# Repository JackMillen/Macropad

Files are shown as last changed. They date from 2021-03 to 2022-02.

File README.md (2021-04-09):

# Macropad
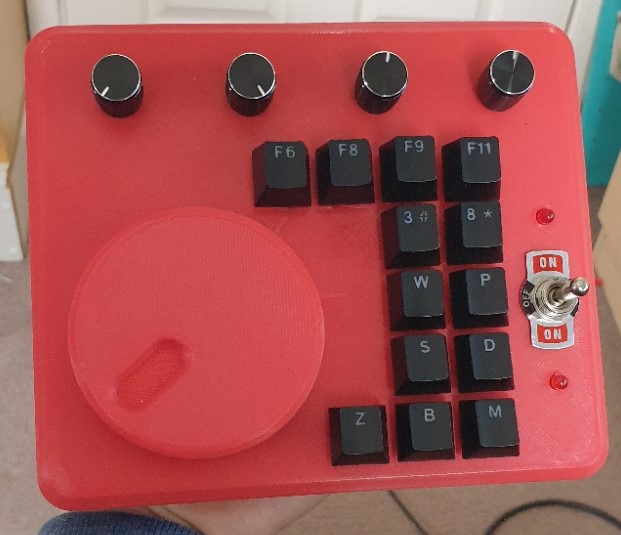
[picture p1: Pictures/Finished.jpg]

## What is it?
This is a small USB Keyboard with rotary encoders designed to have shortcuts assigned to them

It consists of a 3D printed enclosure with 4 Dials, 1 Big Wheel and 13 Mechanical KeySwitches. It also has a 3-Way Switch to switch between button layers. Its powered by a Teensy 4.0 (First time using a teensy and I am hooked)
## WTF was the warning in the description
I don't know what I'm doing. My code works, but it's not written in a way that is particularly understandable. the same applies for my 3D models, I haven't modelled this in a way that's easy to modify. It works enough for me. This project was designed for me to use and no-one else. The only reason this repository exists is a place to store the code. You can do with this how you want. Just be warned.
## Main Principal
The Macropad is recognised by the PC as a keyboard+mouse+joystick+serial device. The buttons on the Macropad output an f13-f24 keypress. Autohotkey listens for these keypresses and outputs the appropriate shortcut. I also added a 3-way switch to the Macropad so you can have different layers to the macros. I use the Serial output as a method of debugging, whenever you press a key, It outputs the letter assigned to the key and the current mode of the 3-Way switch (I know having an open Serial debug interface is a security risk, but it's a keyboard so whatever)
## Precompiled Firmware
I included the precompiled firmware I'm using alongside the source-code. The Firmware.hex is okay, however you might want to change the media keybindings. You almost definitly want to customise the autohotkey script (also both precompiled and Source-code available) since most keys open programs that I use often but most people will have never heard of (e.g. Cura) and the key set to output your email address just prints [EMAIL1] since I'm not sharing my personal email addresses (duh).
## Installing Precompiled Firmware
If for some unholy reason you want to use my precompiled firmware, here it is:
#### Macropad:
  1. Download [Teensy Loader](https://www.pjrc.com/teensy/teensy.exe)
  2. Download Firmware.hex from the Firmware directory
  3. Open Teensy Loader
  4. File/Open HEX file
  5. Press program button on teensy
  6. Press Upload
  7. DONE (LEDs should flash when powered on)
#### Windows:
  1. Win+R
  2. Run "shell:startup"
  3. Copy Macropad.exe into the folder
  4. DONE
## Test Firmware
When I was wiring the Macropad, I wanted to test the connections so I made a test program that just spits out sensor values over serial so they can be read by software like PuTTY or Arduino IDE. This helps find hardware issues with the Button Matrix and Rotary Encoders. Since I haven't uploaded wiring diagrams yet it probably isn't too useful
## Parts List
- 1x Big Wheel.stl
- 1x Top.stl
- 1x Holding Plate.stl
- 1x Base.stl
- 5x KY-040 Rotary encoders
- 1x 3-Way Switch
- 1x Teensy 4.0
- 13x Mechanical Keyswitch (I used Cherry MX Blue)
- 13x 1N4148 Diodes
- 13x Keycaps
- 7x Self Tapping Screws
- Thin insulated wire
- 2x LED
- 2x 200 Ohm Resistors

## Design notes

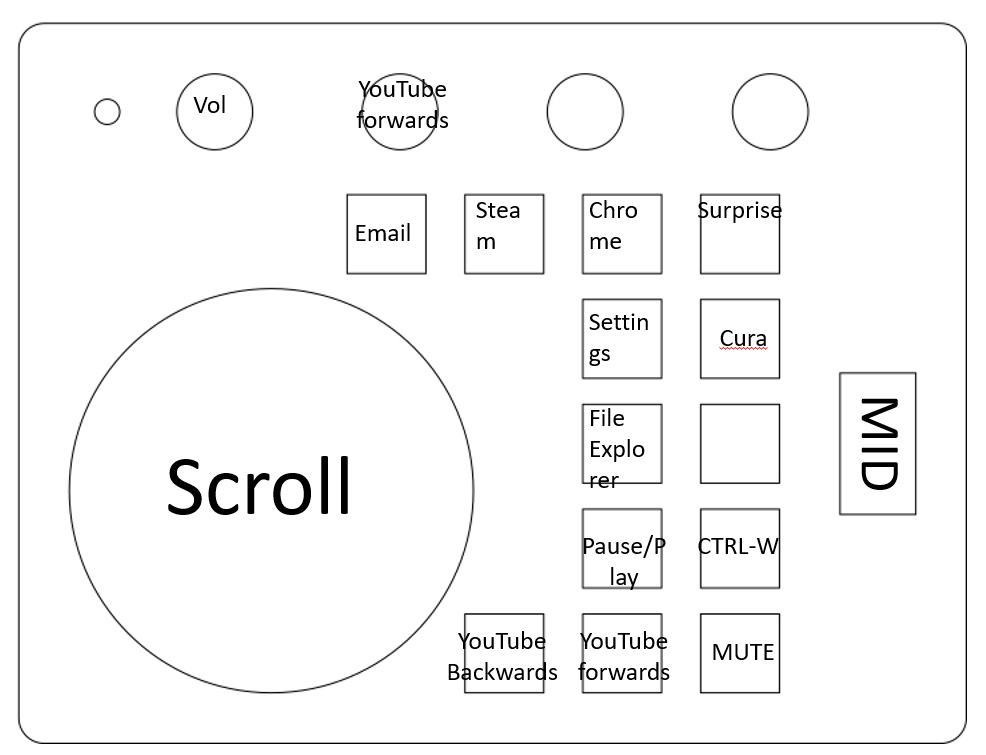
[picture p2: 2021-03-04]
Pictures/Controls.png

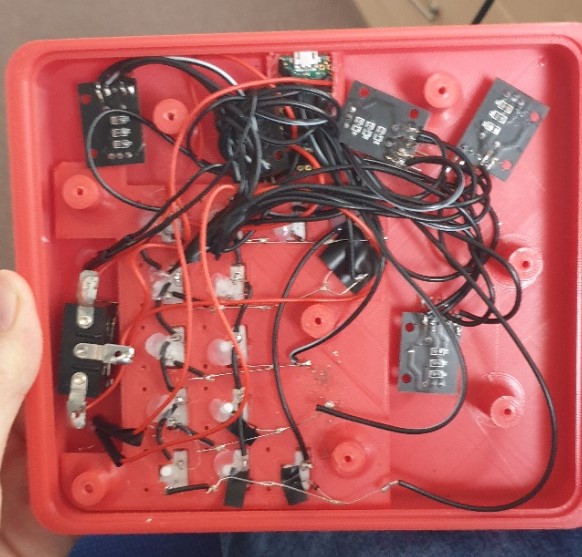
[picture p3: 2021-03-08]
Pictures/Open.jpg

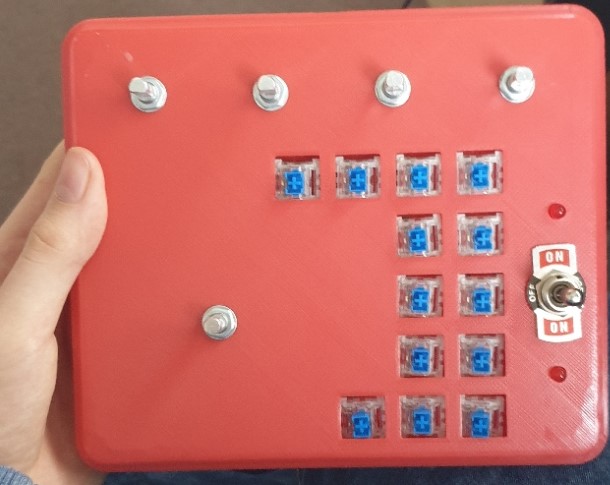
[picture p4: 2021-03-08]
Pictures/Without Keycaps.jpg

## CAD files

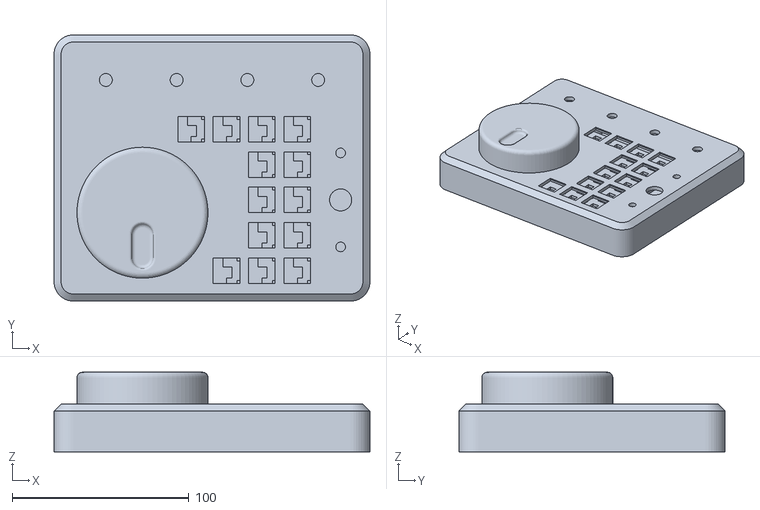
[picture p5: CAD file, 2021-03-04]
3D Models/Full Case.stl
178.6 x 150.5 x 45.0

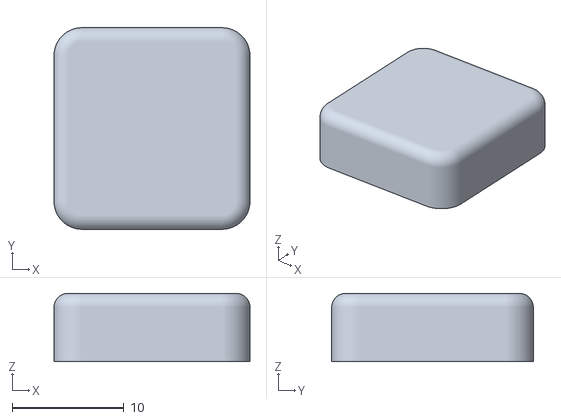
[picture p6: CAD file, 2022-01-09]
3D Models/Keycap.stl
17.5 x 18.0 x 6.10

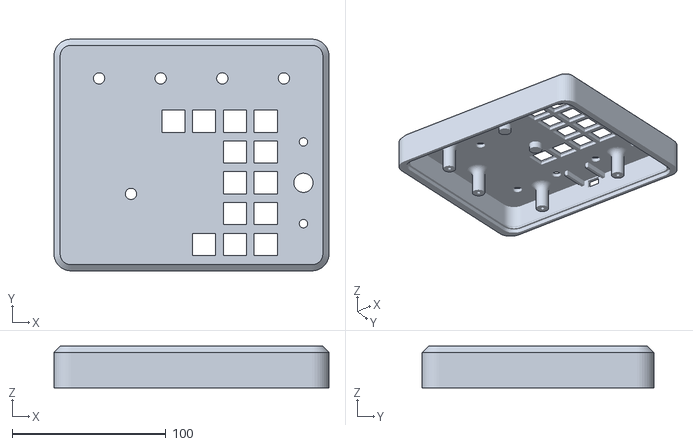
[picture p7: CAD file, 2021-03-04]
3D Models/Top.stl
178.6 x 150.5 x 27.0

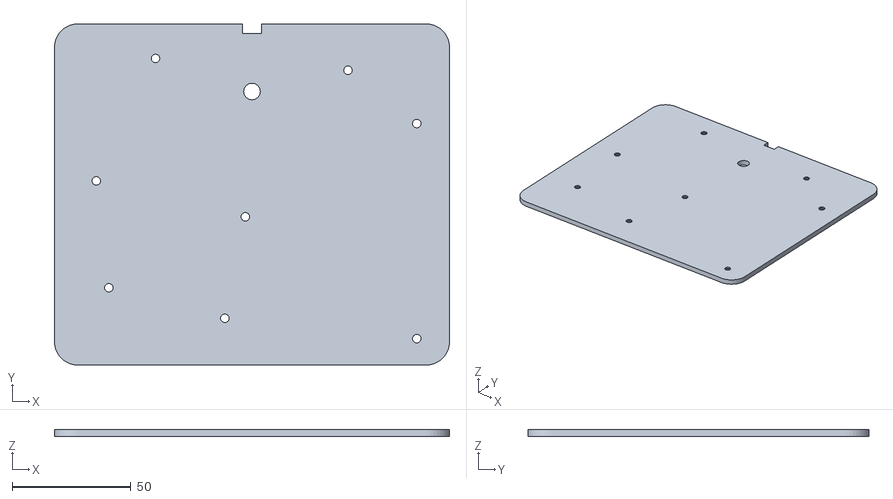
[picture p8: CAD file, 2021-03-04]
3D Models/Base.stl
166.6 x 143.9 x 3.00

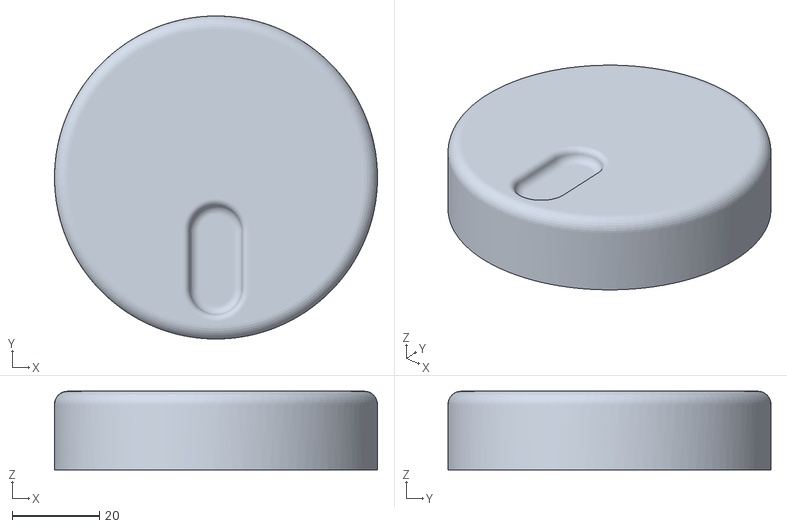
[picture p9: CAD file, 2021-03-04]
3D Models/Big Wheel.stl
74.0 x 74.0 x 18.0

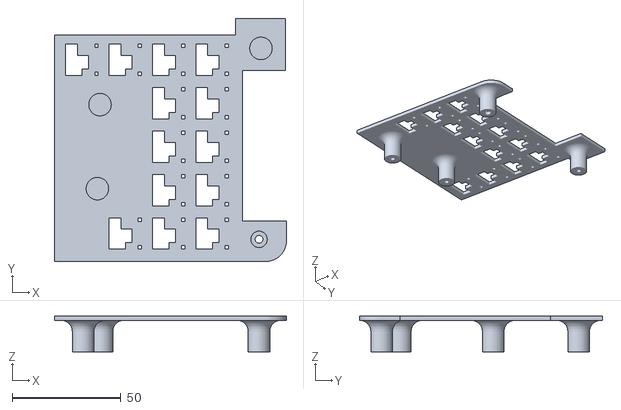
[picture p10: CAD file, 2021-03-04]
3D Models/Holding Plate.stl
106.8 x 111.9 x 16.5

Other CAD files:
3D Models/Macropad.f3d

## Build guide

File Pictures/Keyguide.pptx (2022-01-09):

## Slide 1

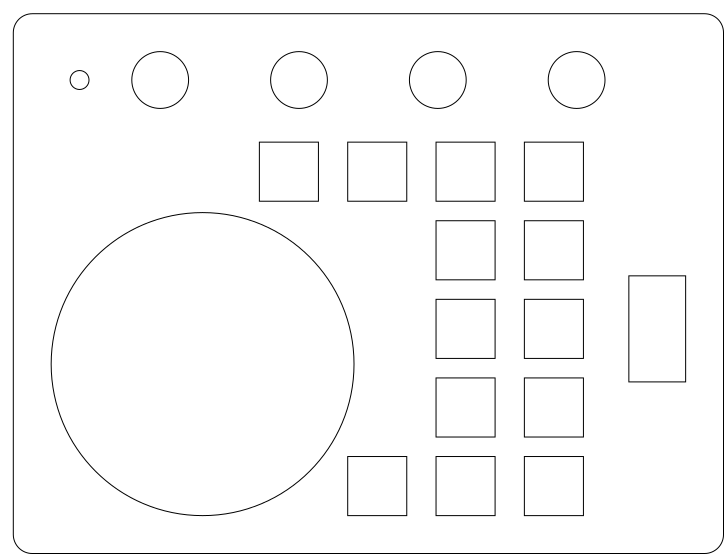
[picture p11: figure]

Vol

YouTube forwards

Email

Steam

Chrome

Task Manager

Rick Roll

Cura

Google Selected

Scroll

File Explorer

Pause/Play

MID

CTRL-W

Full Screen

YouTube Backwards

YouTube forwards

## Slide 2

Vol

Open Arduino

Reverse Indent

Upload

Indent

Scroll

Verify

UP

Monitor

IF

Plotter

Serial print
(SHIFT- no ln)

While

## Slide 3

DOWN

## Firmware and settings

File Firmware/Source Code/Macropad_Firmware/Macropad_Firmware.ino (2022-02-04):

#include <Keypad.h>
#include <Encoder.h>

//Start-Up LED Counter
int x = 0;

//Setting Key Row Variables
const int r1 = 1;
const int r2 = 2;
const int r3 = 3;
const int r4 = 4;
const int r5 = 5;


//Setting Key Column Variables
const int c1 = 6;
const int c2 = 7;
const int c3 = 8;


//Setting Rotary Encoder Variables
const int rot1A = 12;
const int rot1B = 11;
const int rot2A = 14;
const int rot2B = 15;
const int rot3A = 16;
const int rot3B = 17;
const int rot4A = 18;
const int rot4B = 19;
const int rot5A = 21;
const int rot5B = 20;


//Setting 3-Way Switch Variables
const int sw1 = 9; //Up
const int sw2 = 10; //Down


//Setting LED Variables
const int led1 = 22; //Up
const int led2 = 23; //Down


//Setting Encoder Classes
Encoder enc1(rot4A, rot4B); //Small 1
Encoder enc2(rot2A, rot2B); //Small 2
Encoder enc3(rot3A, rot3B); //Small 3
Encoder enc4(rot5A, rot5B); //Small 4
Encoder enc5(rot1A, rot1B); //Big Wheel

//Encoder Past
int past1 = 0;
int past2 = 0;
int past3 = 0;
int past4 = 0;
int past5 = 0;

/*
Code I copied and modified from the keypad library because I tried to code it myself but it was so 
inefficient that the serial bus was overwhelmed and I was loosing cycles. I'm so sorry I have failed you senpai
*/
const byte ROWS = 3; 
const byte COLS = 5; 
char hexaKeys[ROWS][COLS] = {
  {'D', 'F', 'H', 'J', 'M'},
  {'C', 'E', 'G', 'I', 'L'},
  {'B', 'A', 'M', 'N', 'K'}
};
byte rowPins[ROWS] = {c1, c2, c3}; 
byte colPins[COLS] = {r1, r2, r3, r4, r5}; 
Keypad customKeypad = Keypad(makeKeymap(hexaKeys), rowPins, colPins, ROWS, COLS); 


void setup() {
  //Starts Serial Debug Response
  Serial.begin(9600);

  //Sets LED and 3-Way pinmodes
  pinMode(sw1, INPUT);
  pinMode(sw2, INPUT);
  pinMode(led1, OUTPUT);
  pinMode(led2, OUTPUT);

  //Activating 3-Way PULLUP resistors
  digitalWrite(sw1, HIGH);
  digitalWrite(sw2, HIGH);

  //LED Starup Animation
  while (x != 4){
    digitalWrite(led1, HIGH);
    delay(100);
    digitalWrite(led2, HIGH);
    delay(100);
    digitalWrite(led1, LOW);
    delay(100);
    digitalWrite(led2, LOW);
    delay(100);
    x = x + 1;
  }

  //Serial Starup Message
  Serial.println("----------------------------------");
  Serial.println("-----Macropad V1.3 Alpha 2022-----");
  Serial.println("----------By Jack Millen----------");
  Serial.println("----------------------------------");
}

void loop() {

  
  //More sample code I copied and modified from the Keypad library
  char customKey = customKeypad.getKey();
  if (customKey){
    //Prints Mode when key is pressed
    if (digitalRead(sw1) == 0) {Serial.println("Mode: ▲");}
    else if (digitalRead(sw2) == 0) {Serial.println("Mode: ▼");}
    else {Serial.println("Mode: -");}
    
    //Prints what key has been pressed
    Serial.println(customKey);

    //Key actions
    if (digitalRead(sw1) == 0) {  // Switch UP
      if (customKey == 'A'){}
      if (customKey == 'B'){}
      if (customKey == 'C'){}
      if (customKey == 'D'){Keyboard.press(KEY_F21);Keyboard.release(KEY_F21);} //Open Arduino IDE
      if (customKey == 'E'){Keyboard.press(KEY_TAB);Keyboard.release(KEY_TAB);} //Indent
      if (customKey == 'F'){Keyboard.set_modifier(MODIFIERKEY_SHIFT);Keyboard.press(KEY_TAB);Keyboard.release(KEY_TAB);Keyboard.set_modifier(0);Keyboard.send_now();} //Reverse Indent
      if (customKey == 'G'){Keyboard.set_modifier(MODIFIERKEY_CTRL);Keyboard.press(KEY_R);Keyboard.release(KEY_R);Keyboard.set_modifier(0);Keyboard.send_now();} //Verify
      if (customKey == 'H'){Keyboard.set_modifier(MODIFIERKEY_CTRL);Keyboard.press(KEY_U);Keyboard.release(KEY_U);Keyboard.set_modifier(0);Keyboard.send_now();} //Upload
      if (customKey == 'I'){Keyboard.set_modifier(MODIFIERKEY_CTRL | MODIFIERKEY_SHIFT);Keyboard.press(KEY_M);Keyboard.release(KEY_M);Keyboard.set_modifier(0);Keyboard.send_now();} //Monitor
      if (customKey == 'J'){Keyboard.set_modifier(MODIFIERKEY_CTRL | MODIFIERKEY_SHIFT);Keyboard.press(KEY_L);Keyboard.release(KEY_L);Keyboard.set_modifier(0);Keyboard.send_now();} //Plotter
      if (customKey == 'K'){Keyboard.press(KEY_F22);Keyboard.release(KEY_F22);} //Serial Print
      if (customKey == 'L'){Keyboard.press(KEY_F23);Keyboard.release(KEY_F23);} //IF
      if (customKey == 'M'){Keyboard.press(KEY_F24);Keyboard.release(KEY_F24);} //While
      }
    else if (digitalRead(sw2) == 0) { // Switch DOWN
      
      }
    else { // Switch MID
      if (customKey == 'A'){Keyboard.press(KEY_F13);Keyboard.release(KEY_F13);}
      if (customKey == 'B'){Keyboard.press(KEY_F14);Keyboard.release(KEY_F14);}
      if (customKey == 'C'){Keyboard.press(KEY_F15);Keyboard.release(KEY_F15);}
      if (customKey == 'D'){Keyboard.press(KEY_F16);Keyboard.release(KEY_F16);}
      if (customKey == 'E'){Keyboard.press(KEY_F17);Keyboard.release(KEY_F17);}
      if (customKey == 'F'){Keyboard.press(KEY_F18);Keyboard.release(KEY_F18);}
      if (customKey == 'G'){Keyboard.press(KEY_F19);Keyboard.release(KEY_F19);}
      if (customKey == 'H'){Keyboard.press(KEY_F20);Keyboard.release(KEY_F20);}
      if (customKey == 'I'){Keyboard.press(KEY_MEDIA_PLAY_PAUSE);Keyboard.release(KEY_MEDIA_PLAY_PAUSE);}
      if (customKey == 'J'){Keyboard.set_modifier(MODIFIERKEY_CTRL);Keyboard.press(KEY_W);Keyboard.release(KEY_W);Keyboard.set_modifier(0);Keyboard.send_now();}
      if (customKey == 'K'){Keyboard.press(KEY_LEFT);Keyboard.release(KEY_LEFT);}
      if (customKey == 'L'){Keyboard.press(KEY_RIGHT);Keyboard.release(KEY_RIGHT);}
      if (customKey == 'M'){Keyboard.press(KEY_F);Keyboard.release(KEY_F);}
      }
    
  }
  //Setting LED depending on 3-Way position
  if (digitalRead(sw1) == 0) {digitalWrite(led1, HIGH);}
  if (digitalRead(sw1) != 0) {digitalWrite(led1, LOW);}
  if (digitalRead(sw2) == 0) {digitalWrite(led2, HIGH);}
  if (digitalRead(sw2) != 0) {digitalWrite(led2, LOW);}

  //Rotary Encoder Positive Actions
  if (enc1.read()/2> past1){Keyboard.press(KEY_MEDIA_VOLUME_INC);Keyboard.release(KEY_MEDIA_VOLUME_INC);}
  
  if (digitalRead(sw1) == 0){                  //UP
    
  }
  else if (digitalRead(sw2) == 0){             //DOWN
    
  }
  else{                                        //MIDDLE
    if (enc5.read()/2 > past5){Mouse.scroll(-2);}
    if (enc2.read()/2 < past2){Keyboard.press(KEY_LEFT);Keyboard.release(KEY_LEFT);}
  }
  
  //Rotary Encoder Negative Actions
  if (enc1.read()/2< past1){Keyboard.press(KEY_MEDIA_VOLUME_DEC);Keyboard.release(KEY_MEDIA_VOLUME_DEC);}
  
  if (digitalRead(sw1) == 0){                  //UP
    
  }
  else if (digitalRead(sw2) == 0){             //DOWN
    
  }
  else {                                       //MIDDLE
    if (enc5.read()/2 < past5){Mouse.scroll(2);}
    if (enc2.read()/2 > past2){Keyboard.press(KEY_RIGHT);Keyboard.release(KEY_RIGHT);}
  }

  //Setting past rotary encoder values
  past1 = enc1.read()/2;
  past2 = enc2.read()/2;
  past3 = enc3.read()/2;
  past4 = enc4.read()/2;
  past5 = enc5.read()/2;

  delay(50);
}

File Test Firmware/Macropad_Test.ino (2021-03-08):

/*
Macropad Test Firmware v0.8
*/
//Setting Row Pin Variables
const int r1 = 1;
const int r2 = 2;
const int r3 = 3;
const int r4 = 4;
const int r5 = 5;

//Setting Row Pin Variables
const int c1 = 6;
const int c2 = 7;
const int c3 = 8;

int A = 0;
int B = 0;
int C = 0;
int D = 0;
int E = 0;
int F = 0;
int G = 0;
int H = 0;
int I = 0;
int J = 0;
int K = 0;
int L = 0;
int M = 0;

void setup() {
  //Setting Serial Baud to 9600
  Serial.begin(9600);

  //Set pin modes
  pinMode(c1, INPUT);
  pinMode(c2, INPUT);
  pinMode(c3, INPUT);
  pinMode(r1, OUTPUT);
  pinMode(r2, OUTPUT);
  pinMode(r3, OUTPUT);
  pinMode(r4, OUTPUT);
  pinMode(r5, OUTPUT);

  //Activating INPUT pull-up resistors by setting to HIGH. Setting OUTPUT to HIGH
  digitalWrite(c1, HIGH);
  digitalWrite(c2, HIGH);
  digitalWrite(c3, HIGH);
  digitalWrite(r1, HIGH);
  digitalWrite(r2, HIGH);
  digitalWrite(r3, HIGH);
  digitalWrite(r4, HIGH);
  digitalWrite(r5, HIGH);
}

void loop(){
  //Polling Row 1 for active switches
  digitalWrite(r1, LOW);
  if (digitalRead(c1) == 0) {A = 1;}
  if (digitalRead(c2) == 0) {B = 1;}
  if (digitalRead(c3) == 0) {C = 1;}
  digitalWrite(r1, HIGH);

  //Polling Row 2 for active switches
  digitalWrite(r2, LOW);
  if (digitalRead(c1) == 0) {D = 1;}
  if (digitalRead(c2) == 0) {E = 1;}
  if (digitalRead(c3) == 0) {F = 1;}
  digitalWrite(r2, HIGH);

  //Polling Row 3 for active switches
  digitalWrite(r3, LOW);
  if (digitalRead(c1) == 0) {G = 1;}
  if (digitalRead(c2) == 0) {H = 1;}
  digitalWrite(r3, HIGH);

   digitalWrite(r4, LOW);
  if (digitalRead(c1) == 0) {I = 1;}
  if (digitalRead(c2) == 0) {J = 1;}
  digitalWrite(r4, HIGH);

  digitalWrite(r5, LOW);
  if (digitalRead(c1) == 0) {K = 1;}
  if (digitalRead(c2) == 0) {L = 1;}
  if (digitalRead(c3) == 0) {M = 1;}
  digitalWrite(r5, HIGH);


  //Debug
  Serial.print(A);
  Serial.print(B);
  Serial.print(C);
  Serial.print(D);
  Serial.print(E);
  Serial.print(F);
  Serial.print(G);
  Serial.print(H);
  Serial.print(I);
  Serial.print(J);
  Serial.print(K);
  Serial.print(L);
  Serial.print(M);
  Serial.println();
  delay(100);

  int A = 0;
  int B = 0;
  int C = 0;
  int D = 0;
  int E = 0;
  int F = 0;
  int G = 0;
  int H = 0;
  int I = 0;
  int J = 0;
  int K = 0;
  int L = 0;
  int M = 0;
}
